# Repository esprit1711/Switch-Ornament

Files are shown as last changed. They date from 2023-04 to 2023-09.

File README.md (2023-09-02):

# Switch-Ornament
tinyest possible Gif Player that looks like a Nintendo Switch
IN CASE YOU WANT TO BUILD YOUR OWN SWITCH ORNAMENT, PLEASE CONTACT ME. I WANT TO FIX SOME TINY PROBLEMS WITH THE BOARD IN VERSION 1.4 :)
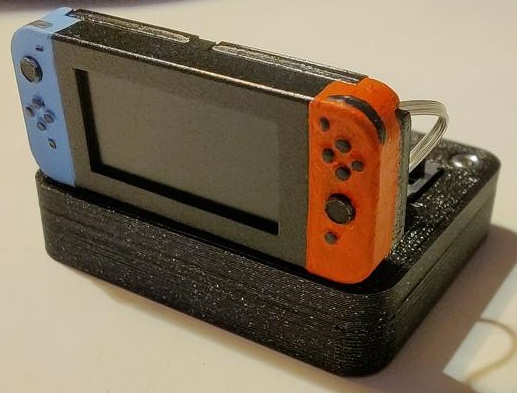
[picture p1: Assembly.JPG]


Here, you will find everything to Copy my GIF Player, that looks like a Nintendo Switch. This Project use a 0.96" 80x160 Pixel TFT with st7735 Driver.
The Source Code is based on the "ESP32-LGFX-SDCard-GifPlayer" Example of the "AnimatedGIF" library from "bitbank2".
The Inspiration for this Project is the Nintendo Switch Ornamend from scottbez1 (you can find his Video in der Credits). He use a slightly bigger Screen, with much higher Resolution but i want the smalest possible Switch.

Part of this Project is a DIY Powerbank only for this device so you can use it as a christmas ornament. Powerbank and Switch are connected over a 65cm long cable with 0.04mm² wires. to achive also the tinyest possible powerbank, i crated a custom Board with Li-Po Charger and Power Switch (you can charge the battery and can still use the device). To use the powerbank also as base, i put 3 magnets inside the switch case and powerbank so it will hold very well together without any bad looking mechanic

The Mainboard is optimised to be ordered at jlcpcb and use the assembly Service. You will find everything jlcpcb need (gerber, BOM and positions file) in the "production" Folder of the KiCad Project. You want to choose a 1.6mm board thickness, the Option "Specify a location" at "Remove Order Number" and check the orientation of every part after upload and check the BOM. You also need to order the tiny Buttons and the TFT so you can assemble it after you got the Boards.

Buttons:

https://de.aliexpress.com/item/1005003752959323.html

0.96" TFT (WELDET TYPE!):

https://de.aliexpress.com/item/1005003806330978.html

After everything is assembled, you need to prepare a USB Cable so the connection will match with the silkscreen. You can solder it directly on the Pads, or use a 1.27mm pinheader. Solder the "BOOT" bridge at the front of the board, connect the USB cable to your PC, open the Firmware with Arduino IDE and upload the Code.
To upload the code, you need to copy the library folder in your local Arduino library folder and install the ESP32 via Board Manager. after you prepared this, you just need to choose the right board (ESP32C3 Dev Module) and Port and set every setting like on the following picture:

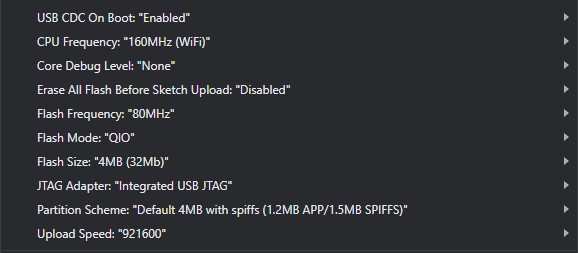
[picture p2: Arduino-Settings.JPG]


After a successful upload, disconnect the USB cable and remove the "BOOT" solder bridge. Now, you dont need to solder the Bridge anymore to upload a Code via USB. You can also disconnect the USB Cable (or leave it, if you want to use it as the power source) and power the device via the +5V and GND Pads. The Software is prepared to update the firmware, if a "SO_update.bin" was found on the SD-Card, so in case of an Update, you dont need the USB connection anymore.

The Case for the powerbank is printed with an FDM 3D Printer. You need 3x M2 Threaded inserts and M2x6mm screws to assemble everything. As a battery, i use 402535 320mAh LiPo. A piece of double sieded tape between the battery and board is recommended.

The magnets i use are 2mm x 1mm (diameter x thickness). Use a pen to mark the polarity, so you know everytime the orientation.

The Case for the Nintendo Switch is printed with an Resin Printer. I had to do some tests to find the perfect dimensions, but now everything should fit very well.
Paint can bring some thickness, so be carefull with to mouch Paint.

Hardware:
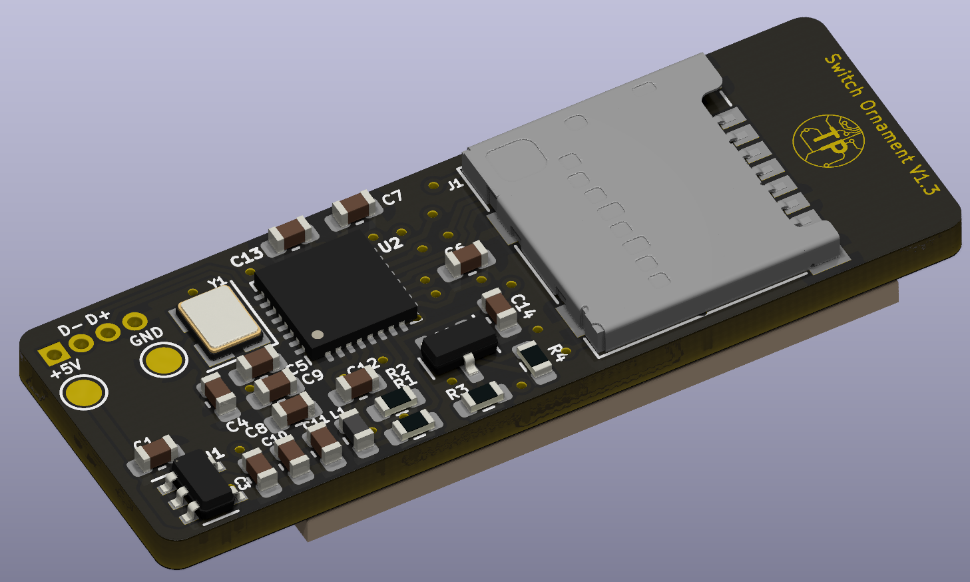
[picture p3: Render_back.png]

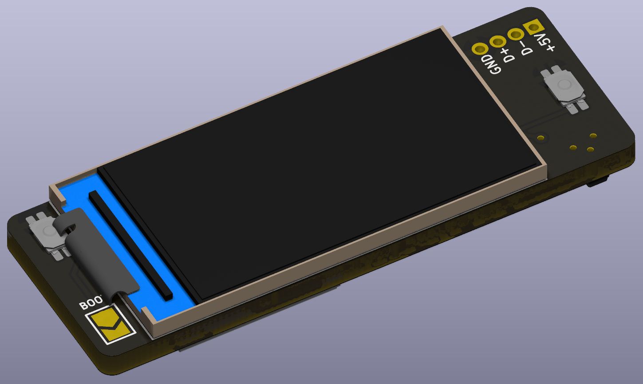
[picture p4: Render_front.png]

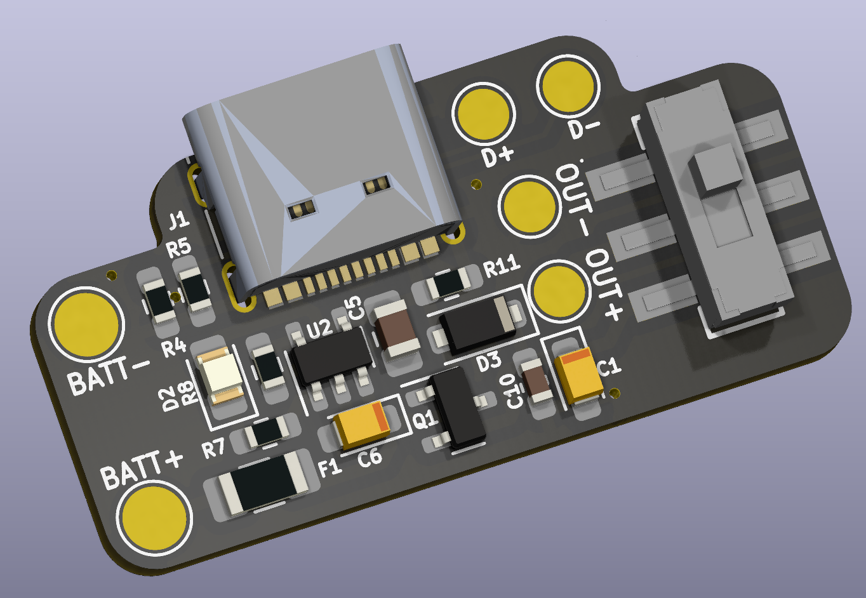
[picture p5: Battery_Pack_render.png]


Changelog:
1.1:
- Support for alternative ST7735 Displays (if Color ist wrong, try GPIO09 connect to VCC (alternative Display Type))

1.2:
- Check for GIF Header. Ignor file if Header ist not "GIF"
- alternative library (chose before compile code)

1.3:
- PNG support
- Left Button trigger play previous file instead of changing the Brightness of the Screen

1.4:
- Clean Code, so it should be now better to maintain
- Fix a problem when use the LGFX library (use a variable from eSPI to initialise the SD Card (old testing stuff))
- improve Version Information and SD Card Info Screen. Its now cleaner and stay for 2 instead of 1 second
- change brightness level by push and hold left (reduce) or right (increase) button for more than 1 second
- speed up initialisation slightly

Credits:

https://github.com/bitbank2/AnimatedGIF

https://github.com/Bodmer/TFT_eSPI

https://www.youtube.com/watch?v=zJxyTgLjIB8

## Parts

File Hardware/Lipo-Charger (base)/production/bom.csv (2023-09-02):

Designator | Footprint | Quantity | Value | LCSC Part #
C1, C6 | CP_EIA-2012-15_AVX-P_Pad1.30x1.05mm_HandSolder | 2 | 10uF
C10 | 0603 | 1 | 100nF
C5 | 0805 | 1 | 1uF
D2 | 0805 | 1 | LED-RT
D3 | D_SOD-123F | 1 | BAT760
F1 | 1206 | 1 | 0,5A
J1 | USB_C_Receptacle_G-Switch_GT-USB-7010ASV | 1 | GT-USB-7010ASV
Q1 | SOT-23 | 1 | Si2307
R11 | 0603 | 1 | 10k
R4, R5 | 0603 | 2 | 5.1k
R7 | 0603 | 1 | 330Ω
R8 | 0603 | 1 | 4,7k
SW1 | JS202011SCQN | 1 | JS202011SCQN
TP1 | TestPoint_Pad_D2.5mm | 1 | BATT+
TP2 | TestPoint_Pad_D2.5mm | 1 | BATT-
TP3 | TestPoint_Pad_D2.0mm | 1 | OUT+
TP4 | TestPoint_Pad_D2.0mm | 1 | D-
TP5 | TestPoint_Pad_D2.0mm | 1 | D+
TP6 | TestPoint_Pad_D2.0mm | 1 | OUT-
U2 | TSOT-23-5 | 1 | LTC4054ES5-4.2

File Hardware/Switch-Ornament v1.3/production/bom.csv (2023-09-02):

Designator | Footprint | Quantity | Value | LCSC Part #
C1, C13, C3, C8 | 0603 | 4 | 1uF
C10, C14 | 0603 | 2 | 10uF
C11, C12, C6, C7 | 0603 | 4 | 100nF
C4, C5 | 0603 | 2 | 16pF
C9 | 0603 | 1 | 10nF
H1 | TestPoint_Pad_D1.5mm | 1 | +5V PAD
H2 | TestPoint_Pad_D1.5mm | 1 | GND PAD
J1 | microSD_HC_Molex_104031-0811 | 1 | 1040310811
J2 | PinHeader_1x04_P1.27mm_Vertical | 1 | ESP32_USB
JP1 | SolderJumper-2_P1.3mm_Open_TrianglePad1.0x1.5mm | 1 | BOOT
L1 | 0603 | 1 | 2.2nH
Q2 | SOT-23 | 1 | T2N7002AK
R1, R2, R4 | 0603 | 3 | 10k
R3 | 0603 | 1 | 20 Ohm
SW1, SW2 | EVPBB | 2 | EVP-BB2A9B000
U1 | TSOP-5_1.65x3.05mm_P0.95mm | 1 | XC6210B332MR-G
U2 | QFN-32-1EP_5x5mm_P0.5mm_EP3.45x3.45mm | 1 | ESP32-C3FN4
U3 | ST7735S 0.96 | 1 | ST7735_0.96"
Y1 | Crystal_SMD_3225-4Pin_3.2x2.5mm | 1 | 7B040000H01

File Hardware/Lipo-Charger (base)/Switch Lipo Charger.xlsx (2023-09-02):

ID | Bezeichner | Footprint | Stückzahl | Bezeichnung | Preis (Stück) | Preis (Gesamt)
1 | J1 | USB_C_Receptacle_G-Switch_GT-USB-7010ASV | 1 | GT-USB-7010ASV | 0.07 € | 0.07 €
2 | U2 | TSOT-23-5 | 1 | LTC4054ES5-4.2 | 0.11 € | 0.11 €
3 | F1 | Fuse_1206_3216Metric_Pad1.42x1.75mm_HandSolder | 1 | 0,5A | 0.01 € | 0.01 €
4 | R8 | R_0603_1608Metric_Pad0.98x0.95mm_HandSolder | 1 | 4,7k | 0.01 € | 0.01 €
5 | C5 | C_0805_2012Metric_Pad1.18x1.45mm_HandSolder | 1 | 1uF | 0.01 € | 0.01 €
6 | R11 | R_0603_1608Metric_Pad0.98x0.95mm_HandSolder | 1 | 10k | 0.01 € | 0.01 €
7 | SW1 | JS202011SCQN | 1 | JS202011SCQN | 0.86 € | 0.86 €
8 | C6,C1 | CP_EIA-2012-15_AVX-P_Pad1.30x1.05mm_HandSolder | 2 | 10uF | 0.03 € | 0.06 €
9 | C10 | C_0603_1608Metric_Pad1.08x0.95mm_HandSolder | 1 | 100nF | 0.01 € | 0.01 €
10 | D3 | D_SOD-123F | 1 | BAT760 | 0.08 € | 0.08 €
11 | R5,R4 | R_0603_1608Metric_Pad0.98x0.95mm_HandSolder | 2 | 5.1k | 0.01 € | 0.02 €
12 | D2 | LED_0805_2012Metric_Pad1.15x1.40mm_HandSolder | 1 | LED-RT | 0.01 € | 0.01 €
13 | Q1 | SOT-23 | 1 | Si2307 | 0.03 € | 0.03 €
14 | R7 | R_0603_1608Metric_Pad0.98x0.95mm_HandSolder | 1 | 330 | 0.01 € | 0.01 €
15 | PCB | PCB | 1 | JLCPCB PCB | 0.66 € | 0.66 €
16 | Akku | 402535 3,7V Lipo 320mAh | 1 | Akku | 1.35 € | 1.35 €
17 | Kabel | 65cm 2x 0,04mm² transparent | 1 | Litze 0,04mm² | 0.29 € | 0.29 €
18 | Gehäuse | 3D Druck (Preis ca.) | 1 | Top/Bottom/etc. | 0.15 € | 0.15 €
19 | Mutter | Einschmelzmuttern | 4 | M2 x D4.0 x L3.0 | 0.05 € | 0.20 €
20 | Magnet | Magnet Rund D2mm H1mm | 3 | 2x1mm | 0.02 € | 0.05 €
 |  |  |  |  | GESAMT: | 4.00 €

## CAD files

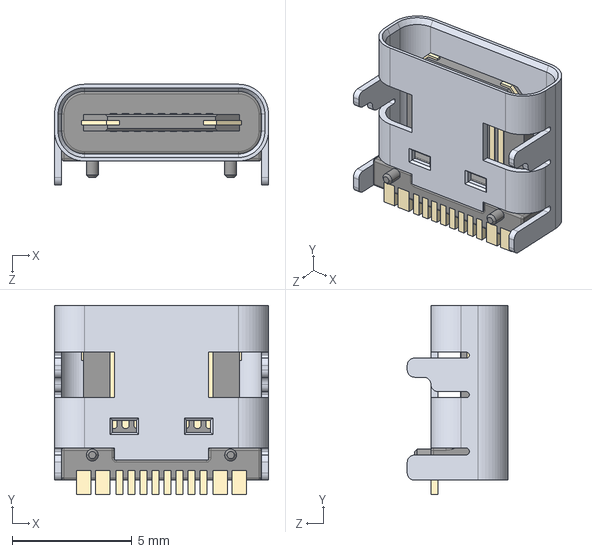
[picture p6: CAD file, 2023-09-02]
Hardware/Lipo-Charger (base)/GT-USB-7010ASV/GT-USB-7010ASV.STEP
8.94 x 7.90 x 4.20 mm

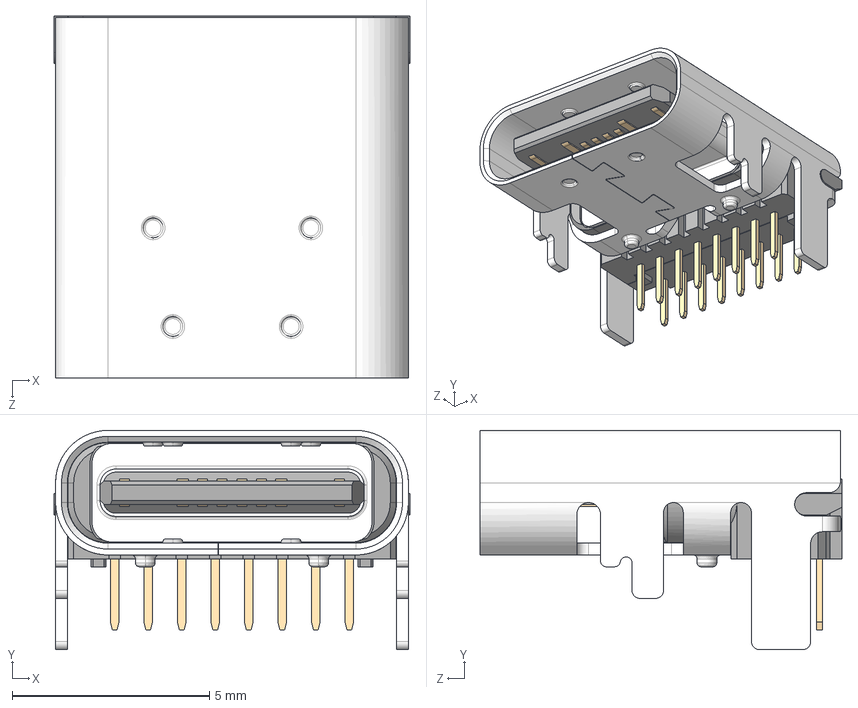
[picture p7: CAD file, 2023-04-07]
Hardware/Lipo-Charger (base)/USB4085-GF-A/3D/USB4085-GF-A.stp
9.03 x 5.56 x 9.17 mm
housing_2

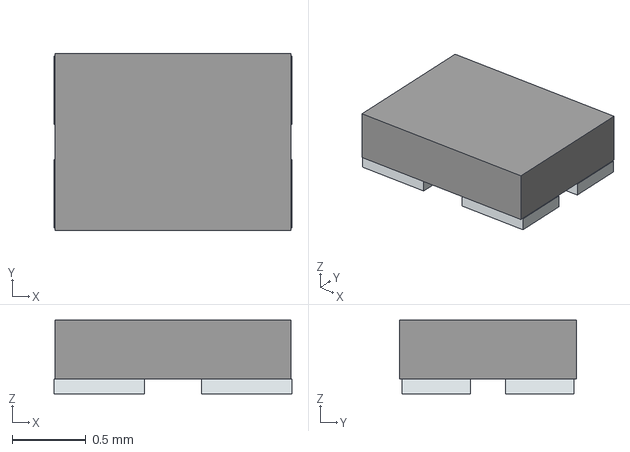
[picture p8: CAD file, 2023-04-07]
Hardware/Switch-Ornament v1.3/Bibliotheken/ABM12W-40.0000MHZ-7-B1U-T3.stp
1.61 x 1.20 x 0.5 mm
Pins

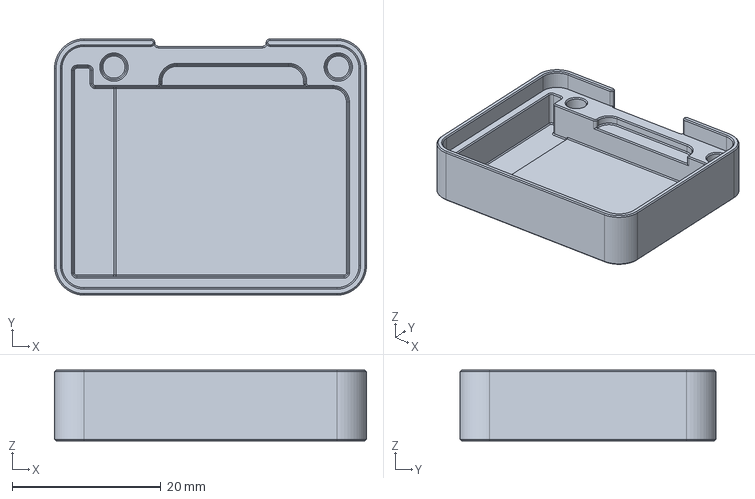
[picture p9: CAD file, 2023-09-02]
Mechanic/Base (Powerbank)/step/Switch Base Part A v1.3.step
42.0 x 34.5 x 9.50 mm

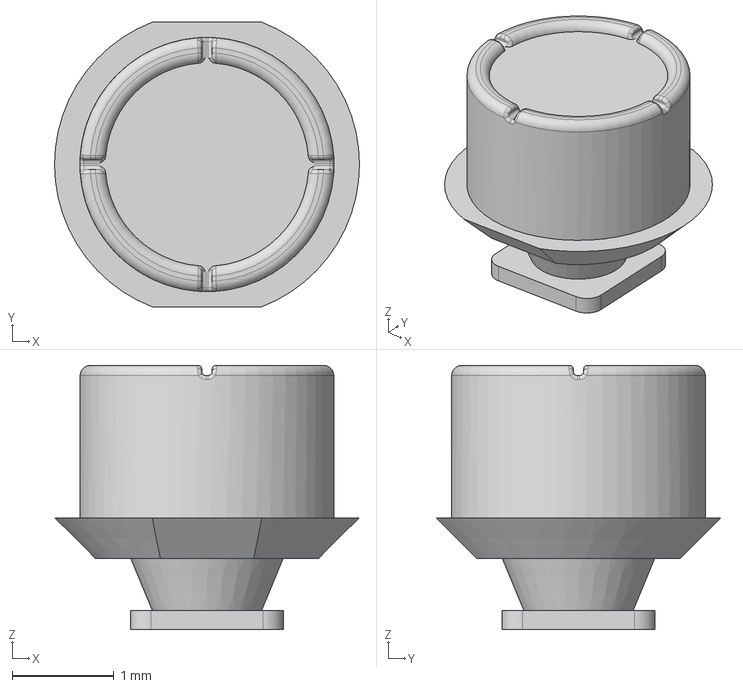
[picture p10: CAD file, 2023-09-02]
Mechanic/Switch-Ornament v1.3/step/Switch-Ornamentv1.3 Part C.step
3.00 x 2.80 x 2.60 mm

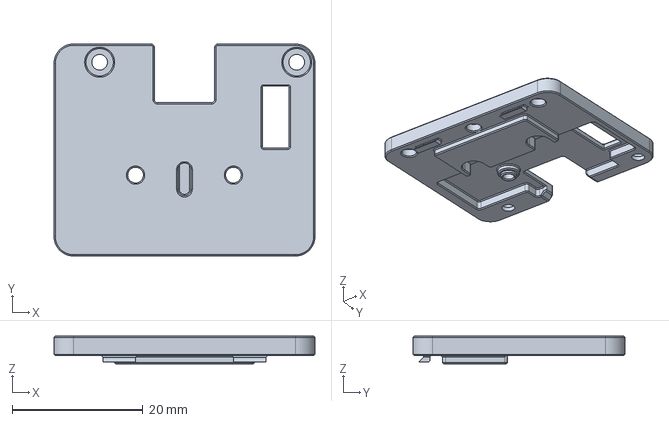
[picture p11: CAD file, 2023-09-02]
Mechanic/Base (Powerbank)/step/Switch Base Part B v1.3.step
40.0 x 32.5 x 4.25 mm

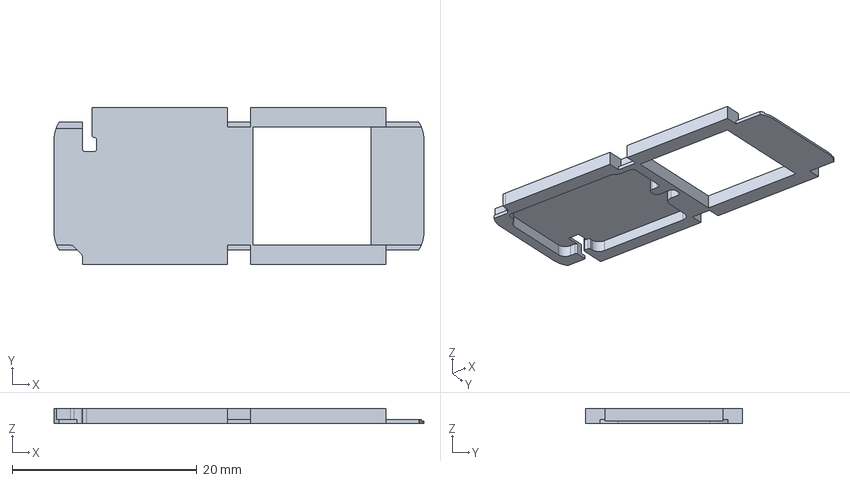
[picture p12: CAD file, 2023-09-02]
Mechanic/Switch-Ornament v1.3/step/Switch-Ornament v1.3 Part B.step
40.0 x 17.0 x 1.60 mm

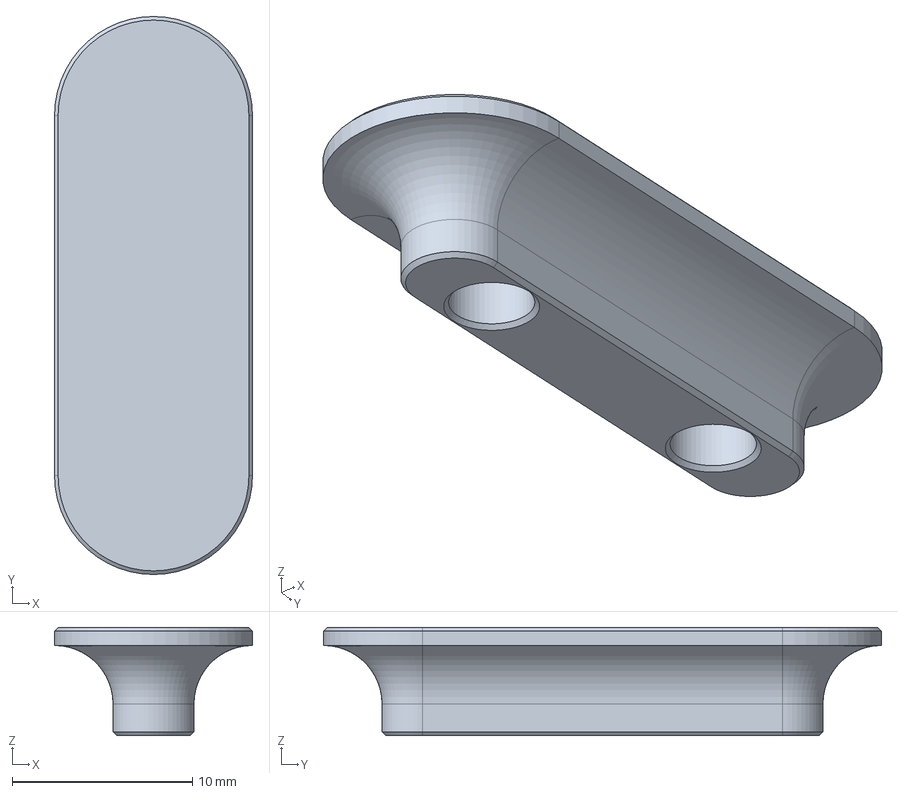
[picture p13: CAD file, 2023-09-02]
Mechanic/Base (Powerbank)/step/Switch Base Part C v1.3.step
11.0 x 31.0 x 6.00 mm

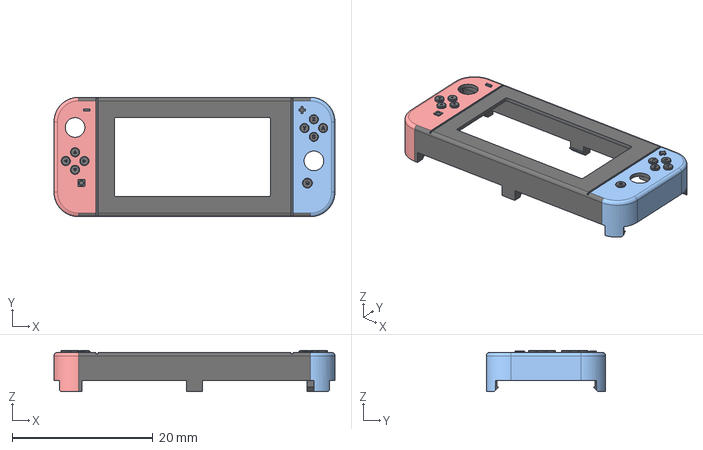
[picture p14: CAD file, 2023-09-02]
Mechanic/Switch-Ornament v1.3/step/Switch-Ornament v1.3 Part A.step
40.0 x 17.0 x 5.90 mm

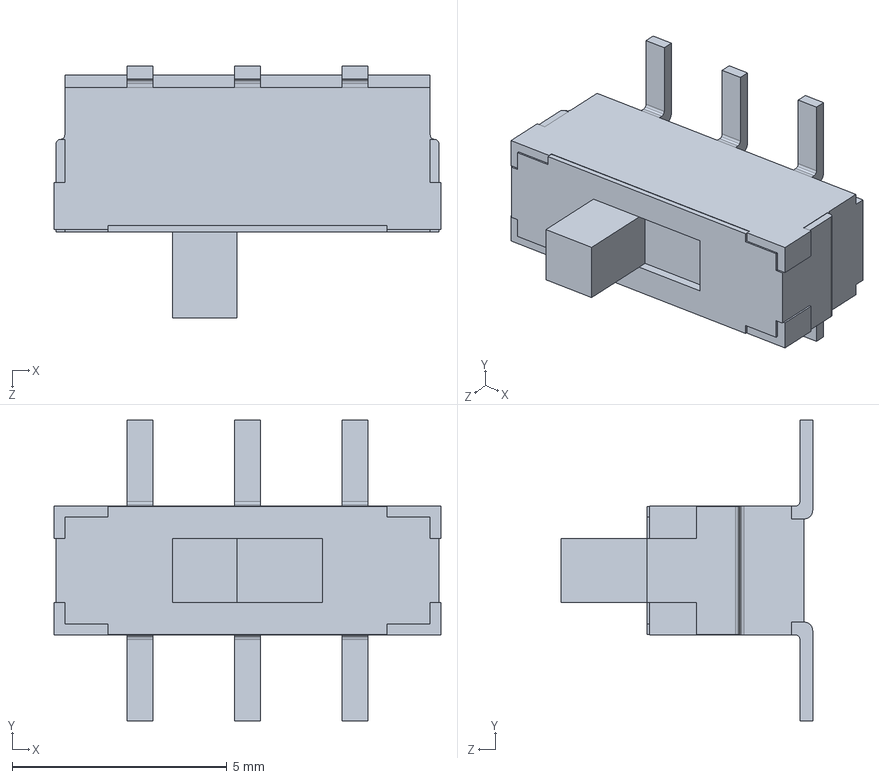
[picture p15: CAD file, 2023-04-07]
Hardware/Lipo-Charger (base)/JS202011SCQN/JS202011SCQN.stp
9.00 x 7.00 x 5.85 mm

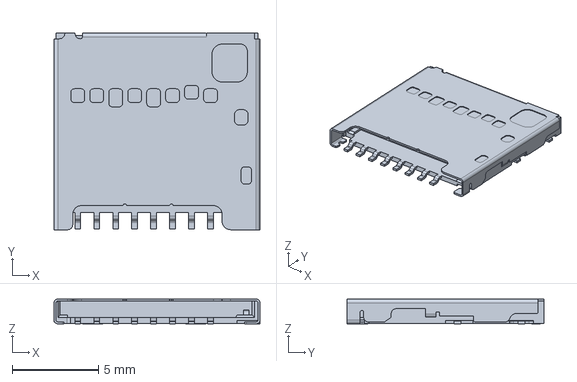
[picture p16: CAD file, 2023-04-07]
Hardware/Switch-Ornament v1.3/Micro-SD_Slot/104031-0811.step
11.9 x 11.4 x 1.45 mm

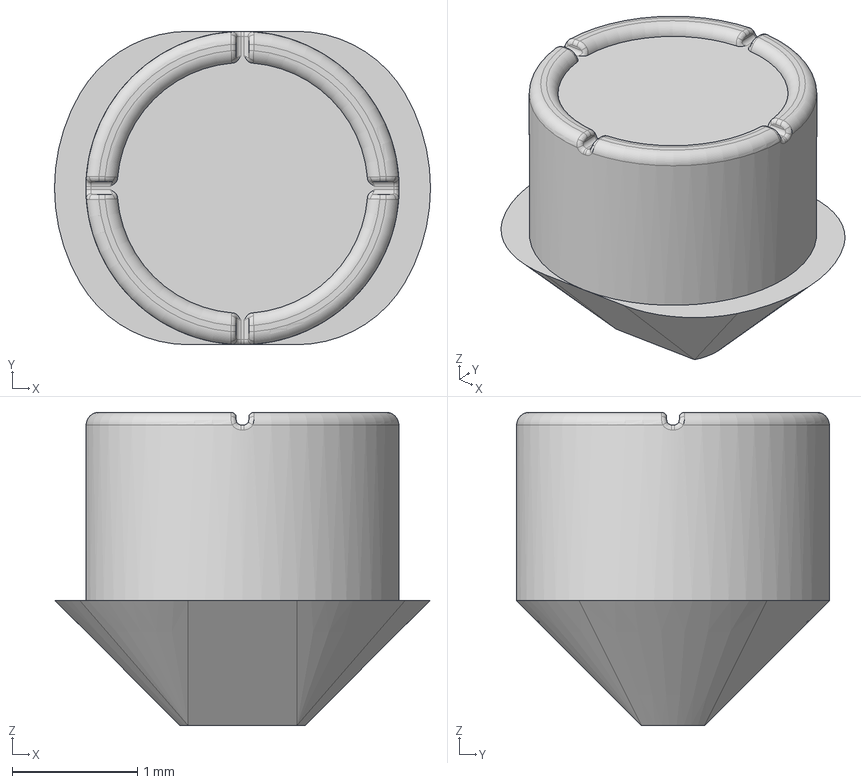
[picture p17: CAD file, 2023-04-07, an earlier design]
Mechanic/Switch-Ornament v1.2/step/Switch-Ornamentv1.2 Part C.step
3.00 x 2.50 x 2.50 mm

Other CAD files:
Mechanic/Switch-Ornament v1.2/step/Switch-Ornament v1.2 Part A.step
Mechanic/Switch-Ornament v1.2/step/Switch-Ornament v1.2 Part B.step
Hardware/Lipo-Charger (base)/Switch Lipo Charger-B_Silkscreen.dxf
Hardware/Lipo-Charger (base)/Switch Lipo Charger-F_Silkscreen.dxf
Hardware/Switch-Ornament v1.3/gerber/Switch-Ornament-B_Silkscreen.dxf
Hardware/Switch-Ornament v1.3/gerber/Switch-Ornament-F_Silkscreen.dxf
Mechanic/Base (Powerbank)/stl/Switch Base Part A v1.3.stl
Mechanic/Base (Powerbank)/stl/Switch Base Part B v1.3.stl
Mechanic/Base (Powerbank)/stl/Switch Base Part C v1.3.stl
Mechanic/Switch-Ornament v1.2/stl/Switch-Ornament v1.2 Part B.stl
Mechanic/Switch-Ornament v1.3/stl/Switch-Ornament v1.3 Part A.stl
Mechanic/Switch-Ornament v1.3/stl/Switch-Ornament v1.3 Part B.stl
Mechanic/Switch-Ornament v1.3/stl/Switch-Ornamentv1.3 Part C.stl

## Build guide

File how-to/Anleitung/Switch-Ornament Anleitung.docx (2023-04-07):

Switch-Ornament

Anleitung

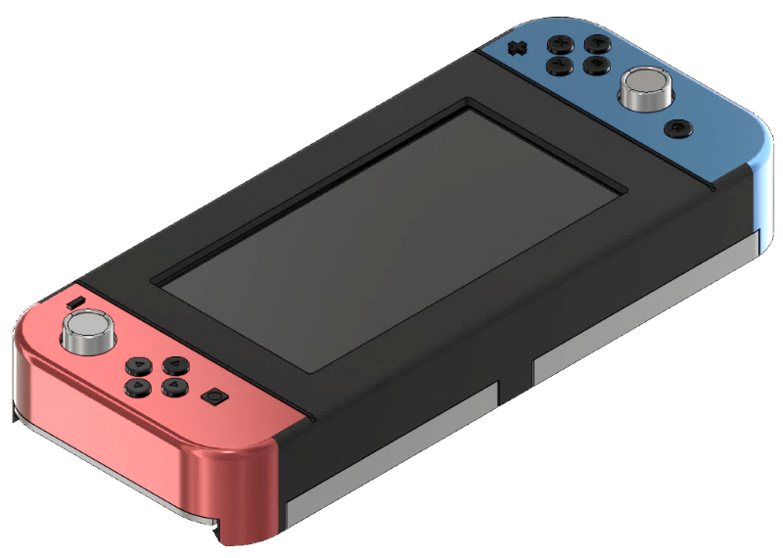
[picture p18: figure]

Gifs vorbereiten:

Gifs können z.B. auf einer der folgenden Seiten gefunden und runtergeladen werden:

- https://giphy.com/
- https://gifer.com/

Tipp: Gifs mit transparentem Hintergrund können unter Umständen nicht richtig dargestellt werden

Damit die Daten richtig dargestellt werden, sollten diese zunächst auf die richtige Auflösung reduziert werden. Dazu eignet sich die Seite https://ezgif.com/resize wo zunächst das gewünschte Gif hochgeladen wird. Im Feld „Width“ wird 160 und im Feld „Height“ wird 80 eingetragen (dies entspricht der Auflösung des Displays in Pixel).

In den meisten Fällen reicht es nun aus auf „Resize image!“ zu drücken. Sieht das gewünschte Ergebnis nicht zufriedenstellend aus, kann unter „If the aspect ratio does not match:“ eine andere Methode zum Verkleinern genutzt werden.

Entspricht die Vorschau dem gewünschten Ergebnis, kann das fertige Gif mit einem Rechtsklick auf die Vorschau und „Bild speichern unter…“ heruntergeladen werden.

Gifs auf SD-Karte kopieren:

Auf die SD-Karte wird ein Ordner mit dem Namen „gif“ erstellt (auf Groß- und Kleinschreibung achten). In diesen Ordner werden die vorbereiteten .gif Daten kopiert. Zum aktuellen Zeitpunkt werden keine anderen Dateitypen unterstützt.

Inbetriebnahme und Steuerung:

Die SD-Karte muss in den SD-Karten Slot eingesetzt werden. Anschließend wird das Gerät über den Schiebeschalter an der Powerbank eingeschaltet. Nach Einlesen der vorhandenen Gifs werden diese nacheinander abgespielt.

Durch Drücken des rechten Analog-Sticks kann das aktuell laufende Gif übersprungen werden.

Durch Drücken des linken Analog-Sticks kann die Helligkeit in 9 Stufen reguliert werden.

Das Kabel zwischen Powerbank und Switch kann komplett abgewickelt werden, damit die Switch z.B. an einen Tannenbaum gehangen werden und die Powerbank dezent im Baum verschwinden kann.

Soll die Switch auf dem Tisch stehen, empfiehlt es sich das Kabel aufgewickelt zu lassen und die Switch über die integrierten Magneten mit dem vorderen Teil der Powerbank zu verbinden.

Geladen wird die Powerbank über ein beliebiges USB-C Kabel, z.B. am PC oder USB-Netzteil. Während des Ladens leuchtet eine rote LED im Bereich des USB-Ports. Ist der Akku vollständig aufgeladen, ist die LED aus, oder glimmt nur noch ganz schwach. Vollständig aufgeladen hält der Akku zwischen 6 und 9 Stunden (je nach Display Helligkeit).

Software-Update:

Ein Software-Update kann über die SD-Karte erfolgen. Dazu wird die Update Datei mit dem Namen „SO_update.bin“ in das Stammverzeichnis der SD-Karte kopiert.

Nach Einsetzen der SD-Karte und anschließendem Starten der Switch, wird das Update automatisch gestartet und durchgeführt. Der Vorgang kann über das Display mitverfolgt werden und sollte in wenigen Sekunden abgeschlossen sein. Die Update Datei wird nach erfolgreichem Update automatisch von der SD-Karte gelöscht.

Werkseinstellungen:

Zum Zurücksetzen des Systems muss zunächst sichergestellt werden, dass die Switch ausgeschaltet ist. Nun den linken und den rechten Analog-Stick gleichzeitig drücken und gedrückt halten. Nun die Switch starten. Die Buttons können nun losgelassen werden. Auf dem Display sollte der Vorgang dargestellt werden.

Allgemeine Informationen:

Der Gif Player ist so programmiert, dass kurze Gifs mehrmals abgespielt werden. Dabei gilt folgende Vorgehensweise:

- Jedes Gif wird maximal 5-mal abgespielt
- Nach jedem Durchlauf wird geprüft, ob das Gif schon insgesamt 3 Sek. lief.
- Läuft das Gif insgesamt 30 sek. wird es forciert abgebrochen und zum nächsten Gif übergegangen

Maximal sollten 10.000 Gifs geladen werden können (nicht getestet). Alle weiteren werden ignoriert

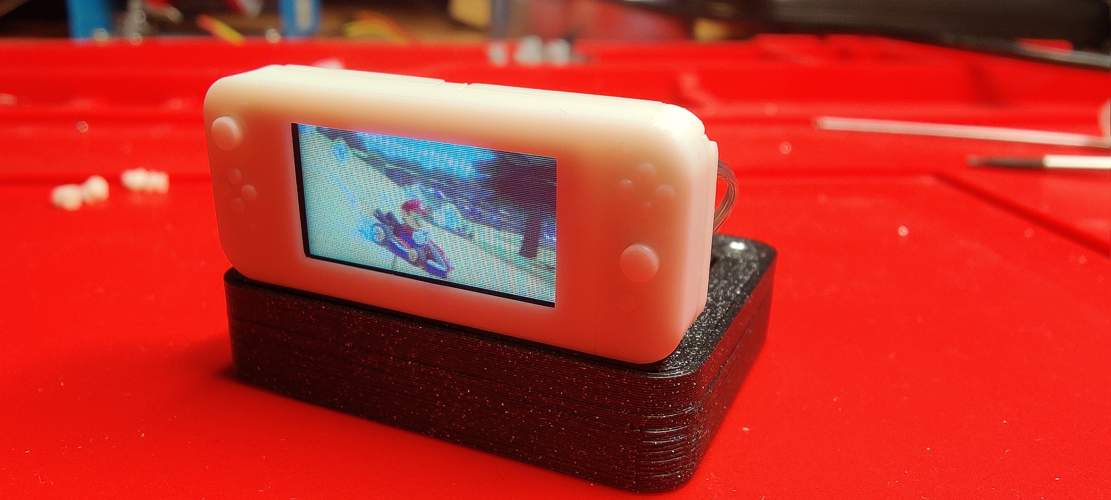
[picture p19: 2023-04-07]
how-to/Pictures/IMG_20230401_151936.jpg

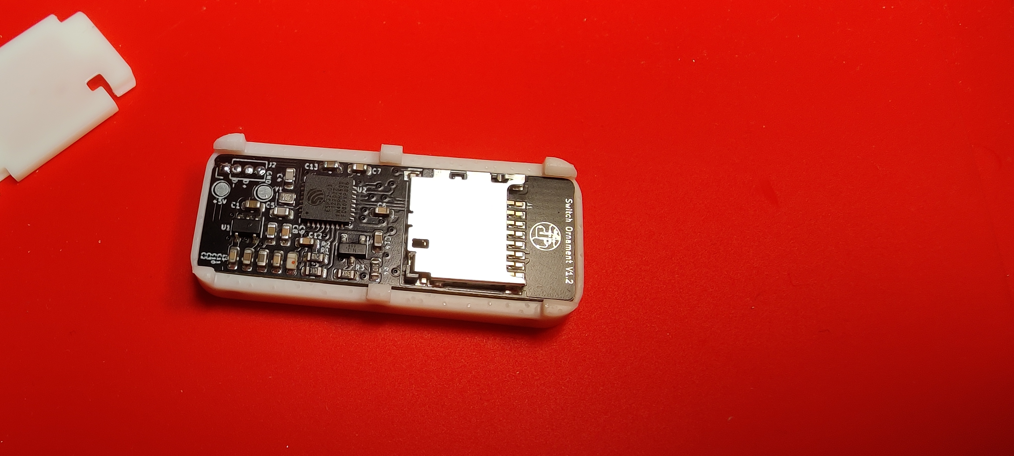
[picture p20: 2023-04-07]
how-to/Pictures/IMG_20230401_151623.jpg

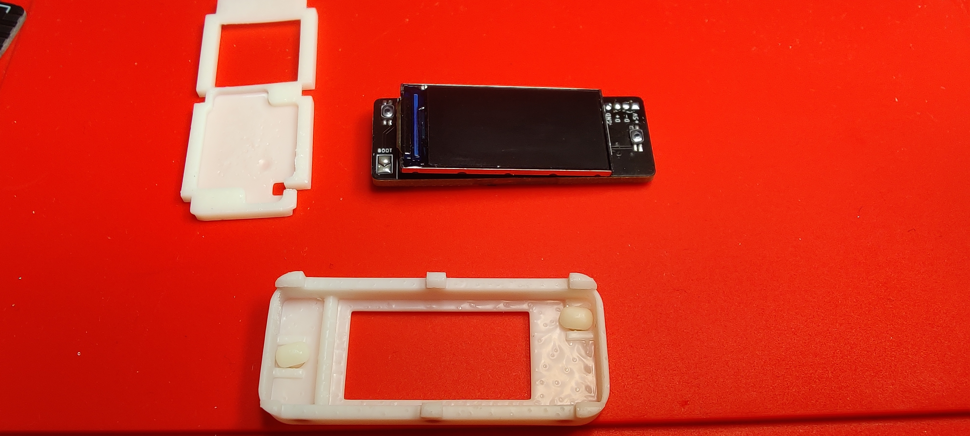
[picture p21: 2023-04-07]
how-to/Pictures/IMG_20230401_150303.jpg

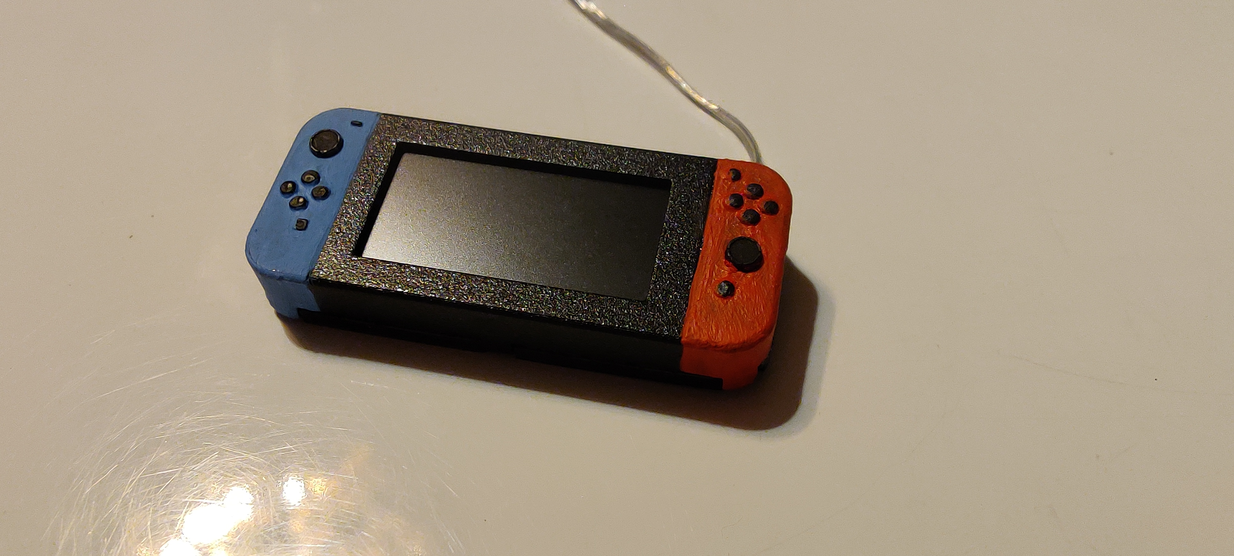
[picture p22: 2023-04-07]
how-to/Pictures/IMG_20230401_194900.jpg

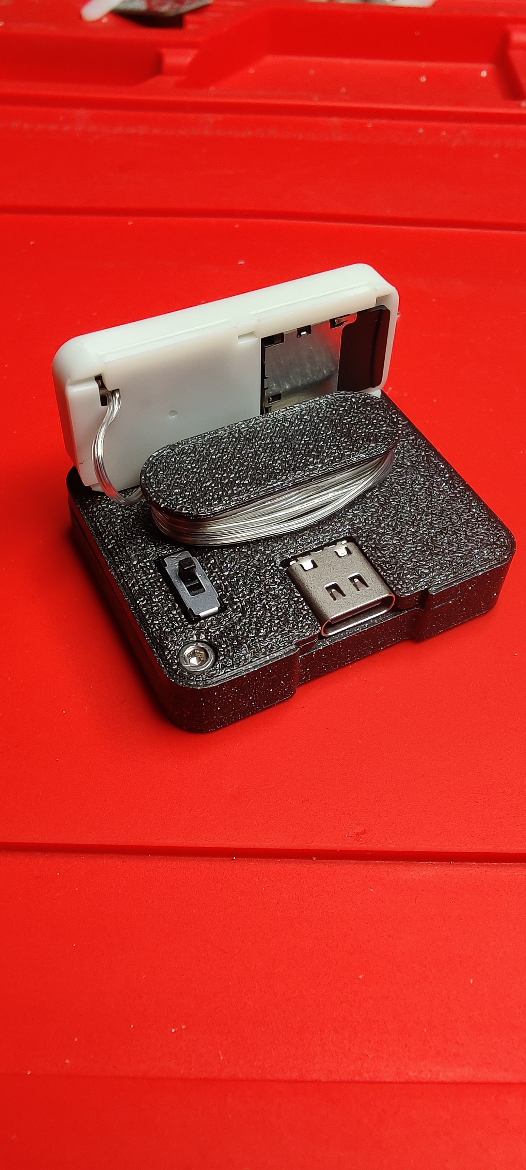
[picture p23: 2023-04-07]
how-to/Pictures/IMG_20230401_152033.jpg

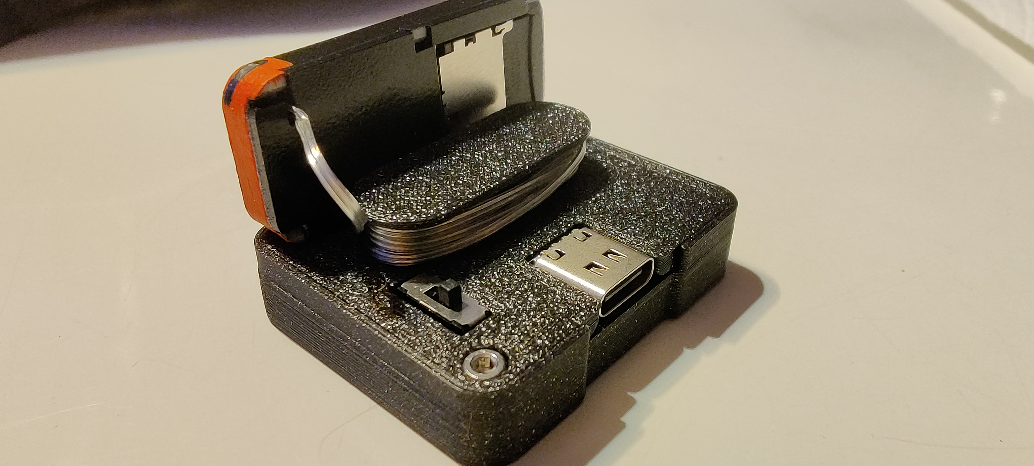
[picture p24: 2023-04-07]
how-to/Pictures/IMG_20230401_195151.jpg

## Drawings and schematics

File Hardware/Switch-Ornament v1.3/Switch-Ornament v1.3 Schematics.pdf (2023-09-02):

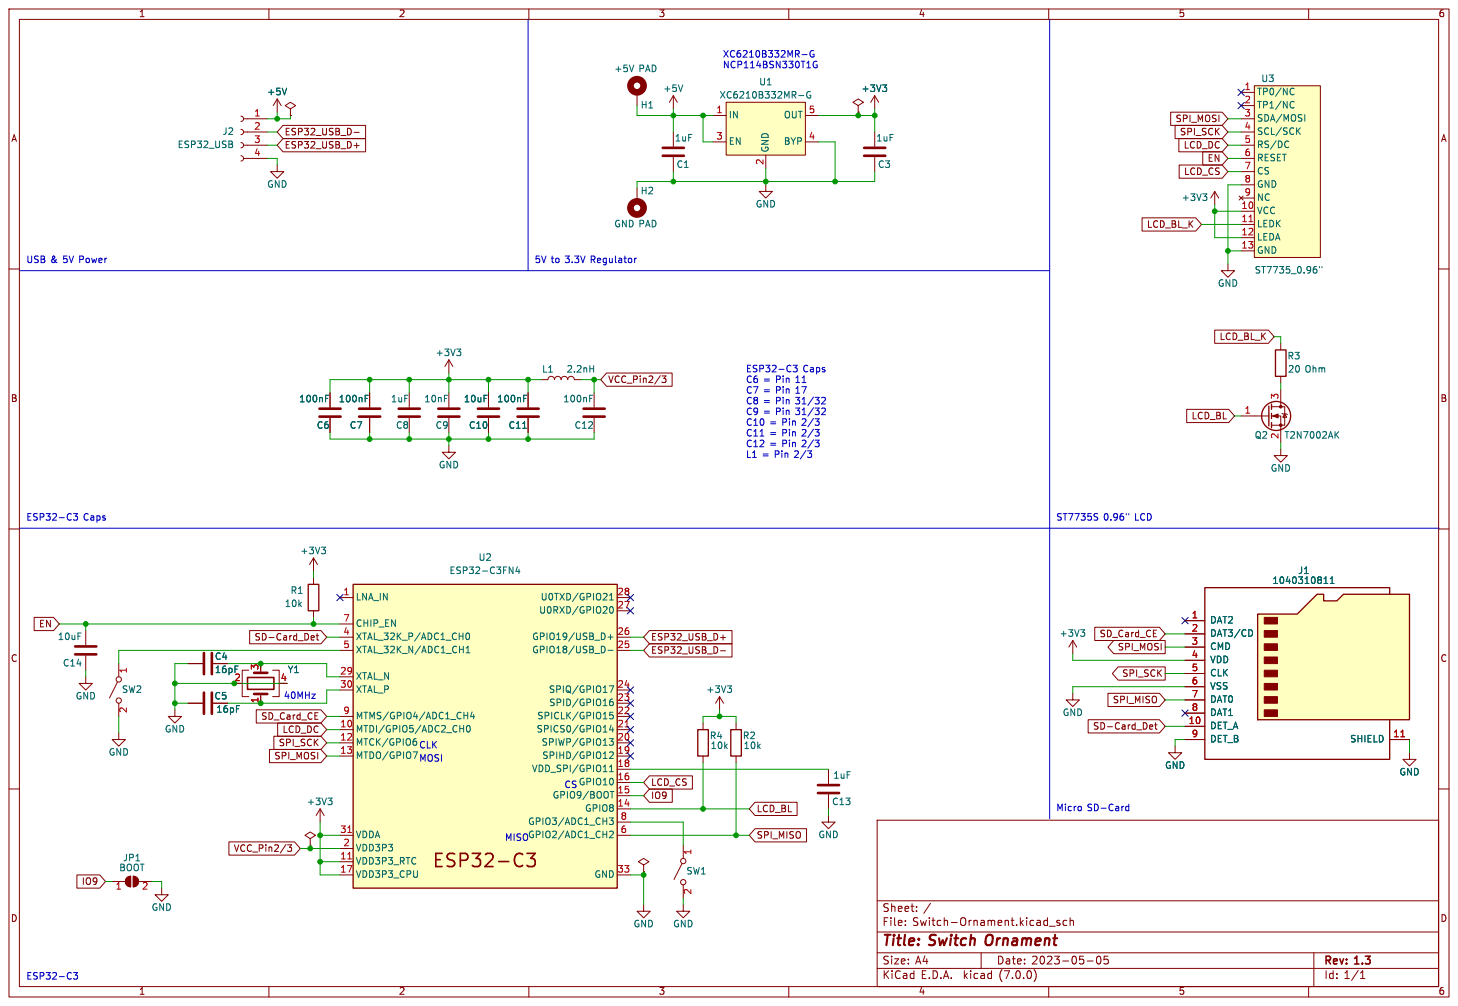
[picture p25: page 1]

1 2 SW2 GND GND GND GND ESP32-C3

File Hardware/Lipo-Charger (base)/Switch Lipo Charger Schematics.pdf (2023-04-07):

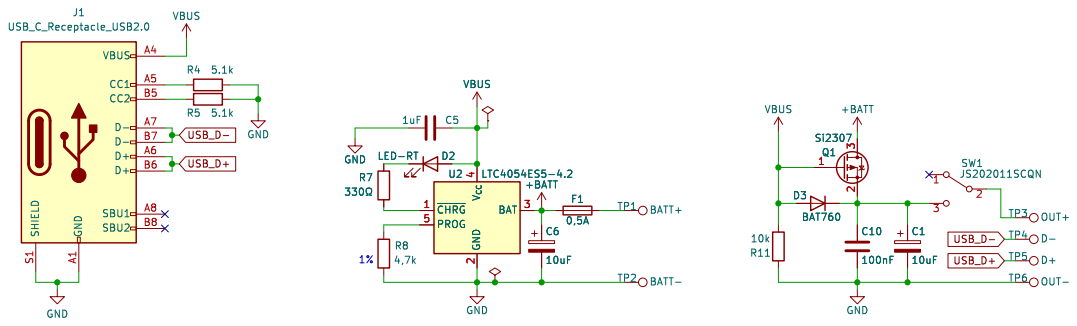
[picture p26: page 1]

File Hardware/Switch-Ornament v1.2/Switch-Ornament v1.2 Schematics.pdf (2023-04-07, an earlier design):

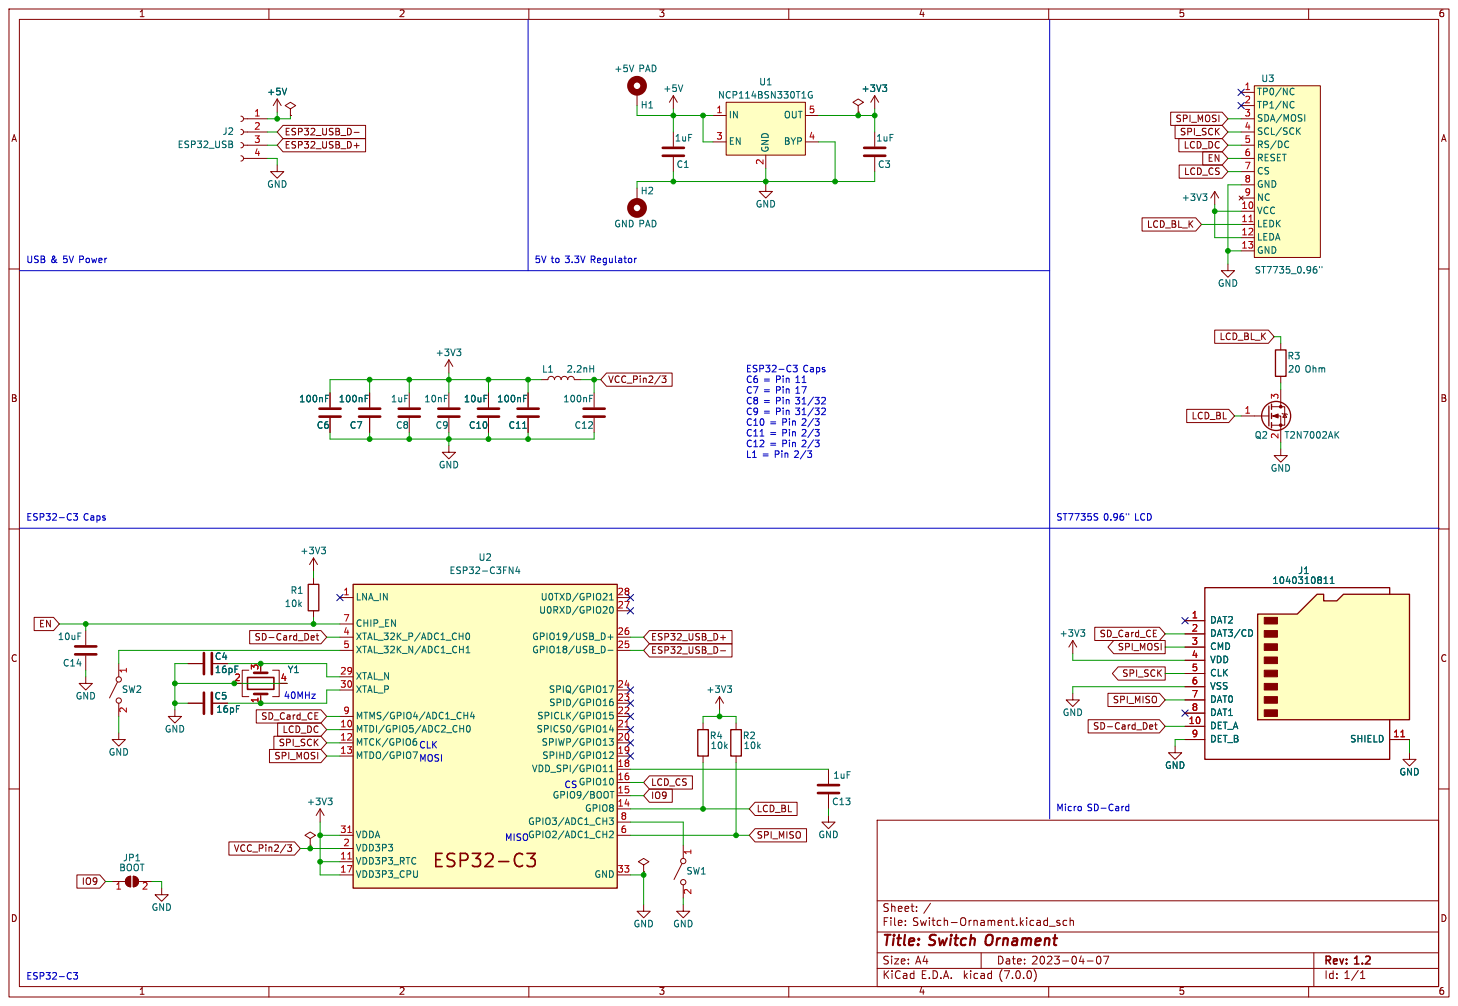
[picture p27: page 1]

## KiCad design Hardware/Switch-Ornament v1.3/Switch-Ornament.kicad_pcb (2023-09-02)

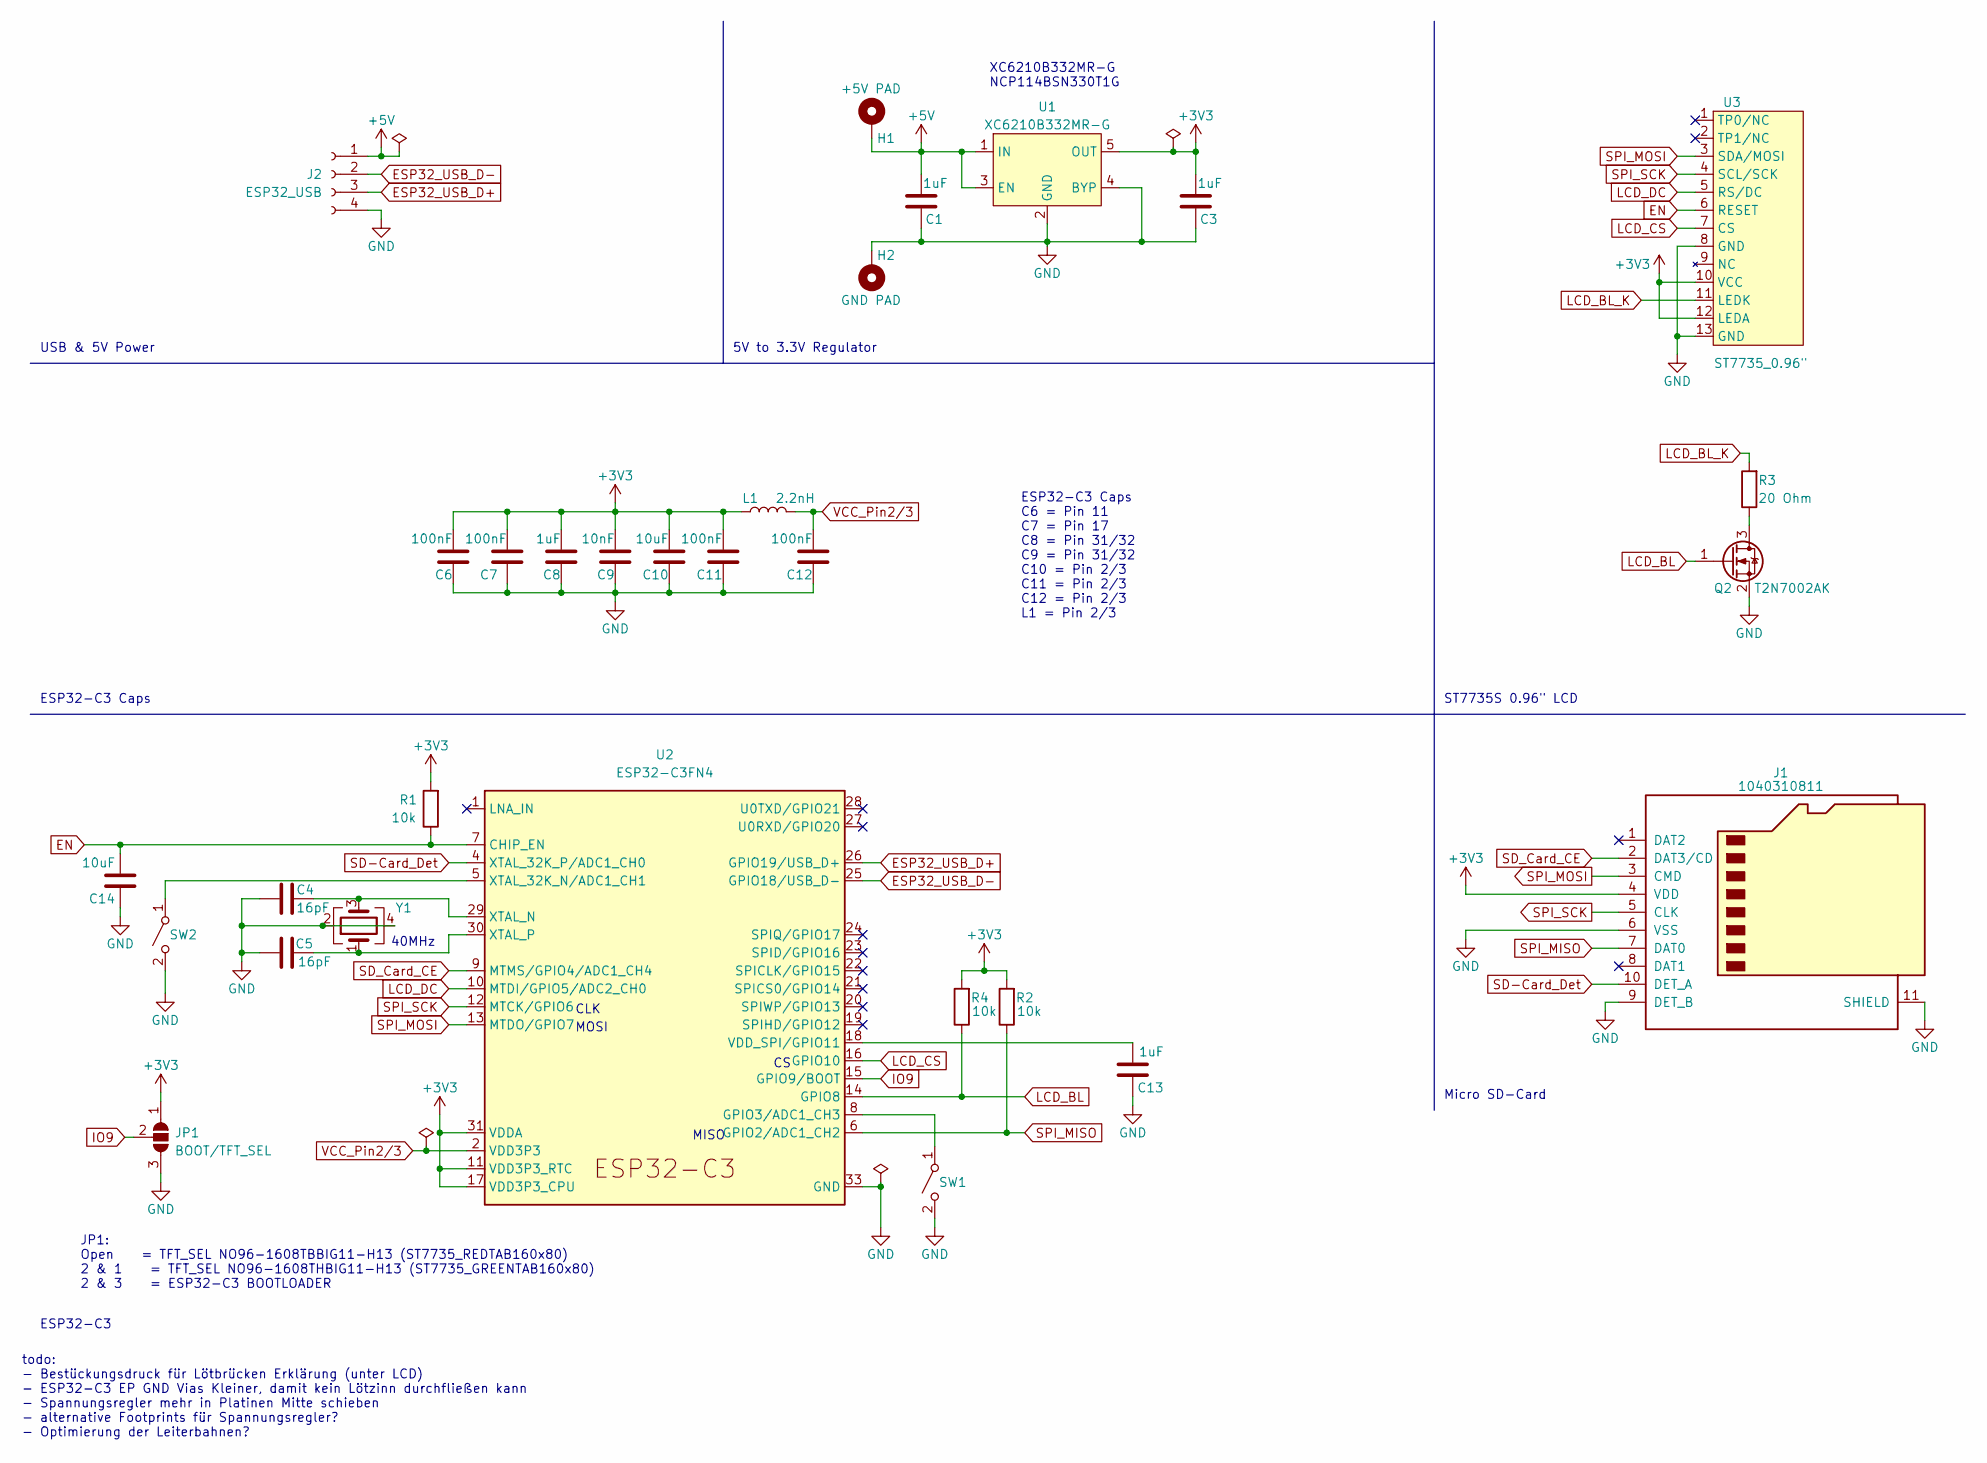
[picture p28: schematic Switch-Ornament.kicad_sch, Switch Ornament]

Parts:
C1, C3, C8, C13: 1uF; C_0603_1608Metric
C4, C5: 16pF; C_0603_1608Metric
C6, C7, C11, C12: 100nF; C_0603_1608Metric
C9: 10nF; C_0603_1608Metric
C10, C14: 10uF; C_0603_1608Metric
H1: +5V PAD; TestPoint_Pad_D1.5mm
H2: GND PAD; TestPoint_Pad_D1.5mm
J1: 1040310811; microSD_HC_Molex_104031-0811
J2: ESP32_USB; PinHeader_1x04_P1.27mm_Vertical
JP1: BOOT/TFT_SEL; SolderJumper-3_P2.0mm_Open_TrianglePad1.0x1.5mm_NumberLabels
L1: 2.2nH; L_0603_1608Metric
Q2: T2N7002AK; SOT-23
R1, R2, R4: 10k; R_0603_1608Metric
R3: 20 Ohm; R_0603_1608Metric
SW1, SW2: EVP-BB2A9B000; EVPBB
U1: XC6210B332MR-G; TSOP-5_1.65x3.05mm_P0.95mm
U2: ESP32-C3FN4; QFN-32-1EP_5x5mm_P0.5mm_EP3.45x3.45mm
U3: ST7735_0.96"; ST7735S 0.96
Y1: 7B040000H01; Crystal_SMD_3225-4Pin_3.2x2.5mm

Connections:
+3V3: C3.2, C6.2, C7.2, C8.2, C9.2, C10.2, C11.2, J1.4 (VDD), JP1.1 (A), L1.1, R1.2, R2.2, R4.2, U1.5 (OUT), U2.11 (VDD3P3_RTC), U2.17 (VDD3P3_CPU), U2.31 (VDDA), U2.32 (VDDA), U3.10 (VCC), U3.12 (LEDA)
+5V: C1.2, H1.1, J2.1, U1.1 (IN), U1.3 (EN)
EN: C14.2, R1.1, U2.7 (CHIP_EN), U3.6 (RESET)
ESP32_USB_D+: J2.3, U2.26 (GPIO19/USB_D+)
ESP32_USB_D-: J2.2, U2.25 (GPIO18/USB_D-)
GND: C1.1, C3.1, C4.2, C5.1, C6.1, C7.1, C8.1, C9.1, C10.1, C11.1, C12.1, C13.1, C14.1, H2.1, J1.6 (VSS), J1.9 (DET_B), J1.11 (SHIELD), J2.4, JP1.3 (B), Q2.2 (S), SW1.2 (B), SW2.2 (B), U1.2 (GND), U1.4 (BYP), U2.33 (GND), U3.8 (GND), U3.13 (GND), Y1.2, Y1.4
IO9: JP1.2 (C), U2.15 (GPIO9/BOOT)
LCD_BL: Q2.1 (G), R4.1, U2.14 (GPIO8)
LCD_BL_K: R3.2, U3.11 (LEDK)
LCD_CS: U2.16 (GPIO10), U3.7 (CS)
LCD_DC: U2.10 (MTDI/GPIO5/ADC2_CH0), U3.5 (RS/DC)
unnamed: Q2.3 (D), R3.1
unnamed: SW1.1 (A), U2.8 (GPIO3/ADC1_CH3)
unnamed: SW2.1 (A), U2.5 (XTAL_32K_N/ADC1_CH1)
unnamed: C13.2, U2.18 (VDD_SPI/GPIO11)
unnamed: C4.1, U2.29 (XTAL_N), Y1.3
unnamed: C5.2, U2.30 (XTAL_P), Y1.1
SD-Card_Det: J1.10 (DET_A), U2.4 (XTAL_32K_P/ADC1_CH0)
SD_Card_CE: J1.2 (DAT3/CD), U2.9 (MTMS/GPIO4/ADC1_CH4)
SPI_MISO: J1.7 (DAT0), R2.1, U2.6 (GPIO2/ADC1_CH2)
SPI_MOSI: J1.3 (CMD), U2.13 (MTDO/GPIO7), U3.3 (SDA/MOSI)
SPI_SCK: J1.5 (CLK), U2.12 (MTCK/GPIO6), U3.4 (SCL/SCK)
VCC_Pin2/3: C12.2, L1.2, U2.2 (VDD3P3), U2.3 (VDD3P3)

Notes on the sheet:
ST7735S 0.96" LCD
CLK
40MHz
USB & 5V Power
XC6210B332MR-G NCP114BSN330T1G
ESP32-C3 Caps
MOSI
Micro SD-Card
todo: - Bestückungsdruck für Lötbrücken Erklärung (unter LCD) - ESP32-C3 EP GND Vias Kleiner, damit kein Lötzinn durchfließen kann - Spannungsregler mehr in Platinen Mitte schieben - alternative Footprints für Spannungsregler? - Optimierung der Leiterbahnen?
ESP32-C3 Caps C6 = Pin 11 C7 = Pin 17 C8 = Pin 31/32 C9 = Pin 31/32 C10 = Pin 2/3 C11 = Pin 2/3 C12 = Pin 2/3 L1 = Pin 2/3
MISO
ESP32-C3
JP1: Open = TFT_SEL NO96-1608TBBIG11-H13 (ST7735_REDTAB160x80) 2 & 1 = TFT_SEL NO96-1608THBIG11-H13 (ST7735_GREENTAB160x80) 2 & 3 = ESP32-C3 BOOTLOADER
5V to 3.3V Regulator

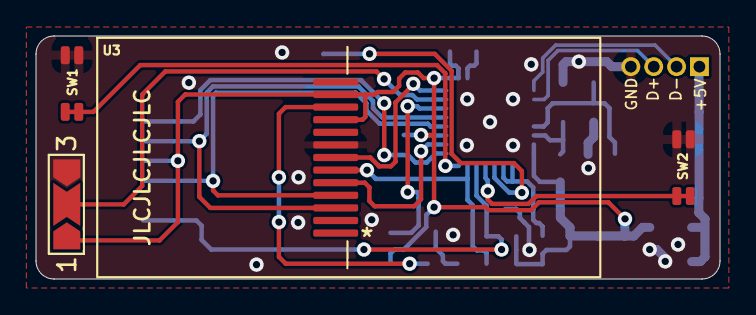
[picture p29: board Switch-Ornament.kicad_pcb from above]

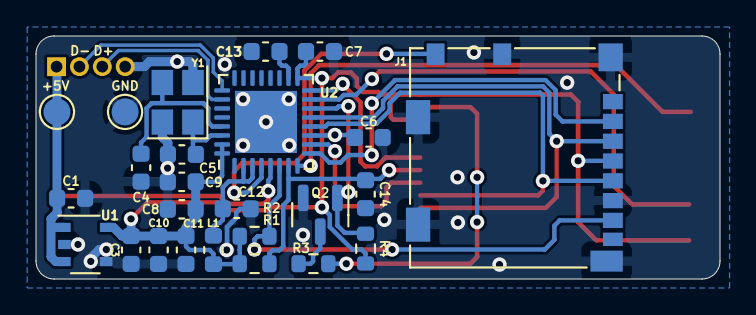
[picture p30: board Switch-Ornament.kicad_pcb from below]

Board: 2 copper layers, 38.0 x 13.5 mm, 30 parts (26 on the bottom side), 23 nets.

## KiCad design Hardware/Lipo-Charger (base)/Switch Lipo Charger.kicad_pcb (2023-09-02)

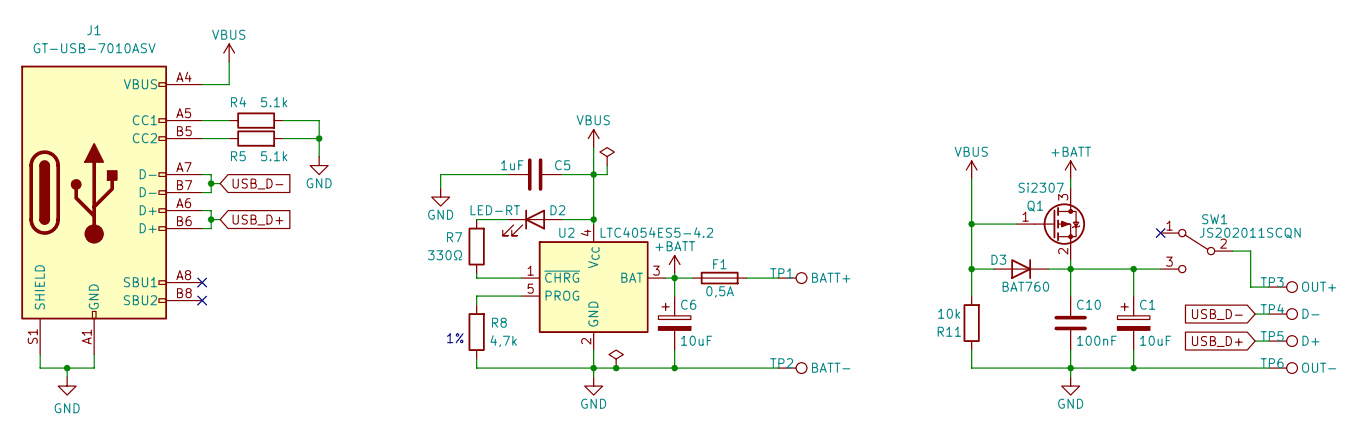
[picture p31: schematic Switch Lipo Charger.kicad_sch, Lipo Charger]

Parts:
C1, C6: 10uF; CP_EIA-2012-15_AVX-P_Pad1.30x1.05mm_HandSolder
C5: 1uF; C_0805_2012Metric_Pad1.18x1.45mm_HandSolder
C10: 100nF; C_0603_1608Metric_Pad1.08x0.95mm_HandSolder
D2: LED-RT; LED_0805_2012Metric_Pad1.15x1.40mm_HandSolder
D3: BAT760; D_SOD-123F
F1: 0,5A; Fuse_1206_3216Metric_Pad1.42x1.75mm_HandSolder
J1: GT-USB-7010ASV; USB_C_Receptacle_G-Switch_GT-USB-7010ASV
Q1: Si2307; SOT-23
R4, R5: 5.1k; R_0603_1608Metric_Pad0.98x0.95mm_HandSolder
R7: 330Ω; R_0603_1608Metric_Pad0.98x0.95mm_HandSolder
R8: 4,7k; R_0603_1608Metric_Pad0.98x0.95mm_HandSolder
R11: 10k; R_0603_1608Metric_Pad0.98x0.95mm_HandSolder
SW1: JS202011SCQN
TP1: BATT+; TestPoint_Pad_D2.5mm
TP2: BATT-; TestPoint_Pad_D2.5mm
TP3: OUT+; TestPoint_Pad_D2.0mm
TP4: D-; TestPoint_Pad_D2.0mm
TP5: D+; TestPoint_Pad_D2.0mm
TP6: OUT-; TestPoint_Pad_D2.0mm
U2: LTC4054ES5-4.2; TSOT-23-5

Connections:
+BATT: C6.1, F1.1, Q1.3 (D), U2.3 (BAT)
GND: C1.2, C5.2, C6.2, C10.2, J1.A1 (GND), J1.A12 (GND), J1.B1 (GND), J1.B12 (GND), J1.S1 (SHIELD), R4.2, R5.2, R8.1, R11.1, TP2.1, TP6.1, U2.2 (GND)
unnamed: D2.1 (K), R7.2
unnamed: C1.1, C10.1, D3.1 (K), Q1.2 (S), SW1.3 (C)
unnamed: F1.2, TP1.1
unnamed: J1.A5 (CC1), R4.1
unnamed: J1.B5 (CC2), R5.1
unnamed: SW1.2 (B), TP3.1
unnamed: R8.2, U2.5 (PROG)
unnamed: R7.1, U2.1 (~CHRG)
USB_D+: J1.A6 (D+), J1.B6 (D+), TP5.1
USB_D-: J1.A7 (D-), J1.B7 (D-), TP4.1
VBUS: C5.1, D2.2 (A), D3.2 (A), J1.A4 (VBUS), J1.A9 (VBUS), J1.B4 (VBUS), J1.B9 (VBUS), Q1.1 (G), R11.2, U2.4 (V_{CC})

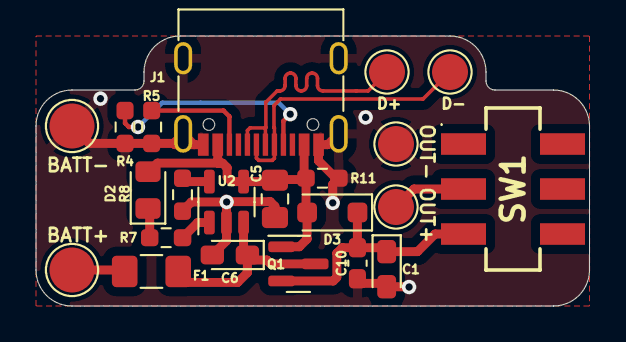
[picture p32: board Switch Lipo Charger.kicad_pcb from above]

Board: 2 copper layers, 30.8 x 15.0 mm, 22 parts (0 on the bottom side), 13 nets.

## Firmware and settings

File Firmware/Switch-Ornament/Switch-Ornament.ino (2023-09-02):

/*
Changelog:
1.1:
- Support for alternative ST7735 Displays (if Color ist wrong, try GPIO09 connect to VCC (alternative Display Type))

1.2:
- Check for GIF Header. Ignor file if Header ist not "GIF"
- alternative library (chose before compile code)

1.3:
- PNG support
- Left Button trigger play previous file instead of changing the Brightness of the Screen

1.4:
- Clean Code, so it should be now better to maintain
- Fix a problem when use the LGFX library (use a variable from eSPI to initialise the SD Card (old testing stuff))
- improve Version Information and SD Card Info Screen. Its now cleaner and stay for 2 instead of 1 second
- change brightness level by push and hold left (reduce) or right (increase) button for more than 1 second
- speed up initialisation slightly
*/

////////// DISPLAY TREIBER //////////
//chose if you want to use the TFT_eSPI (recommended) or the LGFX library
#define use_tft_eSPI_library
//#define use_LGFX_library

////////// VERSION INFORMATIONEN //////////
const String date = "02.09.2023";
const String version = "1.4";

////////// BIBLIOTHEKEN EINBINDEN //////////
#include "SO_TFT.h"
#include "SO_SD.h"
#include "SO_BUTTON.h"
#include "SO_GIF.h"
#include "SO_UPDATE.h"
#include "SO_PNG.h"
#include "SO_SPIFFS.h"
#include "SO_WDT.h"

////////// GLOBALE VARIABLEN DEKLARIEREN //////////
bool interrupt_current_play = false;                                                                // interrupt gif, um aktuelles GIF zu überspringen

////////// SETUP //////////
void setup()
{
  //Serial.begin(115200);
  SO_TFT_SETUP_BL_OFF();
  SO_WDT_SETUP();
  SO_BUTTON_SETUP();
  SO_TFT_CS_HIGH();                                                                                 // ChipSelect Pins zu Begin HIGH um SPI Bus nicht zu blockieren
  SO_SD_CS_HIGH();
  SO_SPIFFS_SETUP();
  SO_TFT_SETUP();

  SO_SD_SETUP();

  tft.setCursor(0,0);
  tft.println("Switch Ornament");
  tft.println("by esprit1711");
  tft.println();
  tft.println("Release: " + version);
  tft.println("Date: " + date);
  delay(2000);

  updateFromFS(SD);                                                                                 // prüfe auf "SO_update.bin" in Stammverzeichnis. wenn vorhanden, Update der Firmware

  GiftotalFiles = getGifInventory("/gif");                                                          // scanne "gif" Ordner auf SD Karte nach vorhandenen gif Daten
  PngtotalFiles = getPngInventory("/png");
  if(GiftotalFiles <= 0 && PngtotalFiles <= 0) GifInventoryError(GiftotalFiles);

  Button_A_pressed_event = false;                                                                   // eventuelle Ergebnisse von Interrupts während Initialisierung zurücksetzen
  Button_B_pressed_event = false;
}

////////// LOOP //////////
void loop()
{
  static int FileTypeRotation = 0;
  if (GiftotalFiles <= 0) FileTypeRotation = 1;                                                     // sollte es keine gif Files geben, mache sofort mit PNG weiter

  tft.fillScreen(TFT_BLACK);                                                                        // Bildschirm schwarz füllen um Pixel Leichen vom jeweils vorherigen gif zu vermeiden
  if(digitalRead(SD_Card_detect) == HIGH) SD_Card_missing();                                        // wenn SD Karte während des Betriebs raus gezogen wird, schicke Programm in dead end

  if(FileTypeRotation == 0) GIF_loop();
  else if (FileTypeRotation == 1) PNG_loop();

  FileTypeRotation = fileRotationHandling(FileTypeRotation);                                        // schalte immer wieder um zwischen gif und png

  Button_A_pressed_event = false;
  Button_B_pressed_event = false;
  interrupt_current_play = false;                                                                   // Variable die den Abbruch der aktuellen Datei anweist wieder zurücksetzen
}

////////// FUNKTIONEN //////////
int fileRotationHandling(int FileTypeRotation)
{
  if(interrupt_current_play == true)                                                                // wenn abspielen der aktuellen Datei angewiesen wurde, feststellen, ob vor oder zurück
  {
    if(Button_A_pressed_event == true)                                                              // zurück schalten
    {
      if ((FileTypeRotation == 0 && PngtotalFiles > 0) || (FileTypeRotation == 1 && GiftotalFiles > 0)) // aktuelle unterbrochene Datei = gif und es gibt mindestens ein PNG, oder aktuell unterbrochene Datei PNG und es gibt mindestens 1 gif
      {
        PngcurrentFile = PngcurrentFile - 1;
        if(PngcurrentFile < 0) PngcurrentFile = PngtotalFiles - 1;
        GifcurrentFile = GifcurrentFile - 1;
        if(GifcurrentFile < 0) GifcurrentFile = GiftotalFiles - 1;
      }
      else if (FileTypeRotation == 0 && PngtotalFiles <= 0)                                         // aktuell gespielte Datei = gif und es gibt kein PNG
      {
        GifcurrentFile = GifcurrentFile - 2;
        if(GifcurrentFile < 0) GifcurrentFile = GiftotalFiles - 1;
      }
      else if (FileTypeRotation == 1 && GiftotalFiles <= 0)                                         // aktuell gespielte Datei = PNG und es gibt kein gif
      {
        PngcurrentFile = PngcurrentFile - 2;
        if(PngcurrentFile < 0) PngcurrentFile = PngtotalFiles - 1;
      }
    }
  }
  if (FileTypeRotation == 0 && PngtotalFiles > 0) FileTypeRotation = 1;                             // wenn letzte abgespielte Datei = gif, schalte auf PNG...
  else if (FileTypeRotation == 1 && GiftotalFiles > 0) FileTypeRotation = 0;                        // ... ansonsten von PNG auf gif
  return FileTypeRotation;
}

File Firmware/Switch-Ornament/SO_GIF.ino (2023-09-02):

int getGifInventory(const char* basePath)                                                         // zählt wie viele Gif Daten gefunden wurden und merkt sich jeden Namen in String Array
{
  tft.fillScreen(TFT_BLACK);
  static File GifRootFolder;                                                                      // zeigt auf Stammverzeichnis der SD Karte
  int GifFiles_counter = 0;                                                                       // zeigt auf Feld in String Array mit Dateinamen und zählt anzahl ermittelter gif Daten
  String checkFileType = "";                                                                      // zwischenspeicher um auf Dateityp zu prüfen
  String FileTypeHeader = "";
  GifRootFolder = SD.open(basePath);

  if(!GifRootFolder)                                                                              // prüfe ob gif ordner existiert und geöffnet werden kann. wenn nicht, abbruch und aufrufendes Programm über Problem informieren
  {
    log_n("Failed to open directory");
    return -1;
  }
  if(!GifRootFolder.isDirectory())
  {
    log_n("Not a directory");
    return -1;
  }

  File file = GifRootFolder.openNextFile();                                                       // öffne erste Datei in gif Ordner

  tft.setTextColor(TFT_WHITE, TFT_BLACK);                                                         // vorbereite Darstellung von Anzahl gefundener gif Daten
  tft.setTextSize(2);

  int textPosX = tft.width()/2 - 16;                                                              // Text Zentrieren und ausgabe der ersten Zeile
  int textPosY = tft.height()/2 - 10;

  tft.drawString("GIF Files:", textPosX-40, textPosY-20 );                                        // Ausgabe von "GIF Files:" Text Mitte oben von Bildschirm

  while(file && GifFiles_counter < GifFiles_size)                                                 // so lange daten geöffnet werden können und maximale anzahl an gif daten nicht überschritten wurden
  {
    if(!file.isDirectory())                                                                       // prüfen ob nächstes geladenes Element ein Ordner ist. wenn ja, überspringen
    {
      checkFileType = "";                                                                         // Variable zum testen von Dateityp frei machen
      FileTypeHeader = "";
      const char* fileName = file.name();                                                         // zwischenspeichern von Dateinamen zum weiteren Auswerten
      for(int i = strlen(fileName) - 4; i < strlen(fileName); i++) checkFileType += fileName[i];  // die letzten 4 Zeichen in Dateinamen auswerten
      if (checkFileType == ".gif" || checkFileType == ".GIF")                                     // prüfen ob Dateiendung wie erwartet ist (.gif)
      {
        for(int i = 0; i < 3; i++) FileTypeHeader += char(file.read());                           // prüfe, ob Header von Datei mit "GIF" beginnt
        if(FileTypeHeader == "GIF")
        {
          GifFiles[GifFiles_counter] = String("/gif/") + file.name();                             // merken des Namens der geladenen Datei
          GifFiles_counter++;
          tft.drawString(String(GifFiles_counter), textPosX, textPosY);                           // darstellen der aktuell gezählten Menge
        }
      }
    }
    file = GifRootFolder.openNextFile();                                                          // öffne nächste Datei in gif Ordner
  }
  file.close();
  GifRootFolder.close();                                                                          // schließe gif Ordner
  log_n("Found %d GIF files", GifFiles_counter);                                                  // ausgabe der Anzahl ermittelter gif Daten an Serielle Schnittstelle
  return GifFiles_counter;                                                                        // Anzahl ermittelter gif Daten an aufrufendes Programm zurückgeben
}

void GifInventoryError(int GiftotalFiles)                                                         // dead end, wenn kein gif Ordner gefunden wurde, oder Inhalt leer ist
{
  tft.fillScreen(TFT_BLACK);

  Button_A_pressed_event = false;                                                                 // eventuelle Ergebnisse von Interrupts zurücksetzen
  Button_B_pressed_event = false;
  tft.fillScreen(TFT_RED);
  tft.setTextColor(TFT_BLACK);
  tft.setTextSize(2);
  tft.setCursor(20,7);
  tft.println("gif folder");
  if(GiftotalFiles < 0)                                                                           // gif Ordner fehlt = ERROR code -1
  {
    tft.setCursor(33,27);
    tft.println("Missing!");
  }
  else if(GiftotalFiles == 0)                                                                     // gif Ordner vorhanden, aber leer oder keine .gif Daten gefunden
  {
    tft.setCursor(45,27);
    tft.println("Empty!");
  }
  tft.setTextSize(1);
  tft.setCursor(27,50);
  tft.println("create gif folder");
  tft.setCursor(8,60);
  tft.println("and fill with .gif files");
  while(1)
  {
    if(Button_A_pressed_event == true || Button_B_pressed_event == true) ESP.restart();           // warte auf drücken von linken oder rechten Button um neustart zu triggern
  }
}
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

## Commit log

2023-04-07 Initial Release
    [104031-0811.step, ABM12W-40.0000MHZ-7-B1U-T3.stp, JS202011SCQN.stp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]
2023-09-02 v1.4 release
    Release of Version 1.4:
    Changelog:
    1.1:
    - Support for alternative ST7735 Displays (if Color ist wrong, try GPIO09 connect to VCC (alternative Display Type))
    1.2:
    - Check for GIF Header. Ignor file if Header ist not "GIF"
    - alternative library (chose before compile code)
    1.3:
    - PNG support
    - Left Button trigger play previous file instead of changing the Brightness of the Screen
    1.4:
    - Clean Code, so it should be now better to maintain
    - Fix a problem when use the LGFX library (use a variable from eSPI to initialise the SD Card (old testing stuff))
    - improve Version Information and SD Card Info Screen. Its now cleaner and stay for 2 instead of 1 second
    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
    [SO_BUTTON.ino, SO_GIF.h, SO_GIF.ino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]
2023-09-02 Update Mechanic and Hardware
    [104031-0811.step, ABM12W-40.0000MHZ-7-B1U-T3.stp, GT-USB-7010ASV.STEP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]
2023-09-02 in case of recreate Switch Ornament - Info
